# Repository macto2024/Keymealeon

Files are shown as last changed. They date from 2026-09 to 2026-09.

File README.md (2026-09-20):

## Inspiration

Imagine a mechanical keyboard with an OLED display built into each keycap, where every key can change based on what you’re doing. 

That was the idea behind Keymaeleon. Instead of memorizing shortcuts or reaching for different controls in every app, we wanted the keyboard itself to understand the current context and show the actions that matter most. 

For developers, that means the keys can react to things like running tests, debugging, Git changes, or errors, and surface useful actions right when they’re needed.

## What it does

Keymaeleon is a mechanical keyboard with an OLED display built into each key.

A desktop app keeps track of what application is currently active and changes both what the keys display and what they actually do.

We focused a lot on VS Code. Depending on what’s happening while you’re coding, the keyboard can show actions like:

* Run Tests
* Debug
* Explain
* Fix
* View Diff
* Approve
* Reject
* Commit

The cool part is that the keyboard can react to more than just which app is open. It can also react to what’s happening inside that app.

For programs we haven’t specifically built support for, we use the OpenAI API to generate a control profile and suggest actions that might be useful.

## How we built it

On the hardware side, we used an Arduino Nano ESP32 connected to mechanical switches and individual OLED displays.

The Arduino is responsible for reading key presses, updating the OLEDs, communicating with the computer over USB serial, and sending keyboard/media HID events.

On the computer, we have a Python service that acts as the main bridge between the keyboard and the software running on the machine.

For VS Code, we built an extension that can see things like the active file, Git state, test results, terminal activity, debugging state, and other workspace information.

That context gets sent to the Python service, which decides what should be shown on the keyboard. We can also use OpenAI to help pick actions that make sense for the current situation.

## Challenges we ran into

One of the hardest parts was figuring out what the keys should actually show.

Knowing that VS Code is open is easy. Knowing that the user just ran a test, got an error, and would probably benefit from a “Fix” or “Explain” button is much harder.

That’s why we ended up focusing heavily on developers and building a VS Code extension. It gave us much better context about what the user was actually doing instead of just knowing which window was in focus.

Another challenge was making the keyboard useful outside of the few programs we had time to build integrations for.

We didn’t want Keymaeleon to only work with a small list of supported apps, so we added a system that detects the active window and can use the OpenAI API to come up with useful controls for unfamiliar applications.

That gave us a way to make the keyboard useful in a lot more situations without manually building a profile for every program.

## Accomplishments that we're proud of

The part we’re most proud of is that Keymaeleon actually exists as working hardware.

It’s not just a mockup of what an adaptive keyboard could look like. The physical keys really update while you use the computer, and their functions can change in the middle of a workflow.

Seeing a real key change from something like “Run Tests” to “Fix” after an error happens is probably the moment where the project started to feel real.

## What we learned

A big thing we learned is that more options don’t automatically make an interface better.

At first, it was tempting to put as many actions as possible on the keyboard. But the more useful version was usually the one that showed a small number of actions that made sense right now.

We also learned a lot of very different things while building this: VS Code extensions, serial communication, USB HID, OLED rendering, WebSockets, and how to use AI in a way that’s constrained enough to produce predictable controls instead of random suggestions.

## What's next for Keymaeleon

There are a lot of directions we’d like to take it.

We want to go deeper on developer workflows with better Git and debugging controls, more Codex integration, and things like Sentry-powered incident workflows.

We’d also like to improve browser awareness and make automatically generated profiles for unsupported applications more capable.

And, eventually, we want to try larger keyboard layouts.

The main idea would stay the same though: instead of having one fixed keyboard for every task, the keyboard should change with what you’re doing.

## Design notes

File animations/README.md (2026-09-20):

# Animation Lab

A separate test sketch and Python GUI for the existing **Arduino Nano ESP32** and two **SSD1306 64 × 32** OLEDs. The main firmware and companion are unchanged. This sketch only animates displays; it sends no keyboard or media actions.

## Flash

1. Stop the normal companion and close Serial Monitor.
2. Open `AnimationTest/AnimationTest.ino` in Arduino IDE.
3. Select **Arduino Nano ESP32**, using **Arduino ESP32 Boards by Arduino**, and install **U8g2 by oliver**.
4. Use the same USB settings as the main sketch: **Normal mode (TinyUSB)**, **By Arduino pin (default)**. Upload.

Wiring is unchanged: left OLED SDA=A4, SCL=A5; right OLED SDA=D4, SCL=D5. Both use address 0x3C on separate buses. Buttons D2 and D3 connect to GND, using internal pull-ups. OLED power is 3.3 V. The sketch retains the project's `64X32_1F` driver. Both displays now use separate ESP32 hardware I²C controllers (`Wire` and `Wire1`) at 400 kHz, with explicit callbacks and the same pins; no rewiring is needed.

## Run

From the repository root:

```bash
.venv/bin/pip install -r animations/requirements.txt
.venv/bin/python animations/animations.py
```

Tk is also required (`sudo apt install python3-tk` on Ubuntu). Without pyserial the GUI still supports previews.

Select or type the serial port, then click **Connect**. Settings are sent automatically as you adjust them. The GUI shows the most recent full-frame transfer time for each display and cumulative I²C transmission errors since boot. Timings remain at the last measured value while a display is idle; they measure transfer duration, not total frame time. **Test press** triggers that key on the board and in the preview; physical button presses also update the preview. You can preview without connecting hardware.

## Effects

- **Invert (hold):** invert the entire image while a physical button is held; release restores it. GUI test presses last 450 ms.
- **Bottom wave:** each press launches another inverted ring from the bottom-middle; existing rings keep moving. Thickness is 1–16 pixels; speed is 5–160 pixels/second.
- **Center ripple:** the same ring grows from the screen center.
- **Wipe:** an inverted vertical band crosses the screen.
- **Dissolve:** a repeatable scattered-pixel transition inverts the image, then restores it.
- **Sparkle:** scattered pixels shimmer; thickness sets density.

Both screens show a play symbol inside a border so the pixel inversion is easy to see. Settings apply to both screens, but buttons animate independently. Bottom waves stack independently on every press, with up to 32 waves per key (the oldest is replaced at the limit). Overlapping rings merge rather than cancel. Other modes restart on each press. Except for invert, effects run once and finish even if the button is released. Changing settings cancels current effects. Speed affects all timed effects; thickness affects rings, wipe, and sparkle, but does not affect invert or dissolve.

The board runs effects locally and works without the GUI. On boot it defaults to bottom wave, thickness 5, speed 45. Settings are kept in RAM and reset on reboot. The GUI preview uses the same pixel formulas, but USB latency and OLED transfer time can make physical timing differ, especially at high speeds. The hardware-I²C change has not been compiled with the Arduino board toolchain or validated on physical hardware here.

To restore normal macro-key behavior, re-upload `firmware/Keymaeleon/Keymaeleon.ino` and run the normal companion.

## Slow refresh troubleshooting

Re-upload the updated sketch and restart the GUI to use hardware I²C and see transfer timings. The earlier software-I²C implementation uses driver delay constants rather than the `setBusClock()` value, so changing that setting alone does not speed it up. The new callback sets the hardware clock with `Wire.begin(..., I2C_HZ)`; change `I2C_HZ` if testing another rate.

At 400 kHz, 256 bytes plus acknowledgement bits need about 5.8 ms per screen before command/transaction overhead. The animation target remains about 30 FPS. Nonzero I²C errors indicate a communication problem; check the wiring and module pull-ups. Timings substantially above that baseline help distinguish transfer stalls from display scan artifacts.

## Checks and serial protocol

```bash
python3 -m unittest discover -s animations -p 'test_*.py'
```

115200 baud, ASCII lines ending in newline:

- `HELLO` → `ANIMATIONS 1`
- `STATS` → `STATS <left transfer µs> <right transfer µs> <left errors> <right errors>`
- `SET <mode 0..5> <thickness 1..16> <speed 5..160>` → `OK <mode> <thickness> <speed>`
- `TRIGGER <key 0..1>` → `TRIGGERED <key>`
- Physical changes emit `BUTTON <key> <pressed 0..1>` after 25 ms debounce.

Mode numbers follow the effect list above. Overlong lines are discarded, malformed commands return `ERROR command`, and serial processing is bounded to keep button sampling responsive.

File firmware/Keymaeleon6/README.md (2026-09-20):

# Keymaeleon 6 — dual hardware I²C, isolated display buffers

Six OLED keys in two rows of three, using an **Arduino Nano ESP32** and **two TCA9548A multiplexers**, one per hardware I²C interface. Each row has its own worker, U8g2 object, actual framebuffer, staging bitmap and transport counters. Both rows can transmit concurrently.

This revision fixes the earlier implementation's U8g2 shared-memory/shared-transfer-state hazards: `IsolatedDisplay.h` binds an independently owned framebuffer and selects the stateless classic SSD13xx command callback. The user confirmed on 2026-09-19 that replacing faulty displays resolved the mux2 hardware fault. The diagnostics remain available for future checks.

Each press runs the Animation Lab bottom wave: **8 pixels thick, 120 pixels/second**, over the current action pictogram. Waves stack independently, merge on overlap and finish after 450 ms. The sketch sends revision-tagged key presses to `companion/keymaeleon_6.py`, which executes Ubuntu X11 actions. It does not send USB HID keystrokes. Without the companion, displays show Idle; local waves and diagnostics still work. See the [six-key launch instructions and layouts](../../README.md#six-key-version--quick-start).

## Wiring

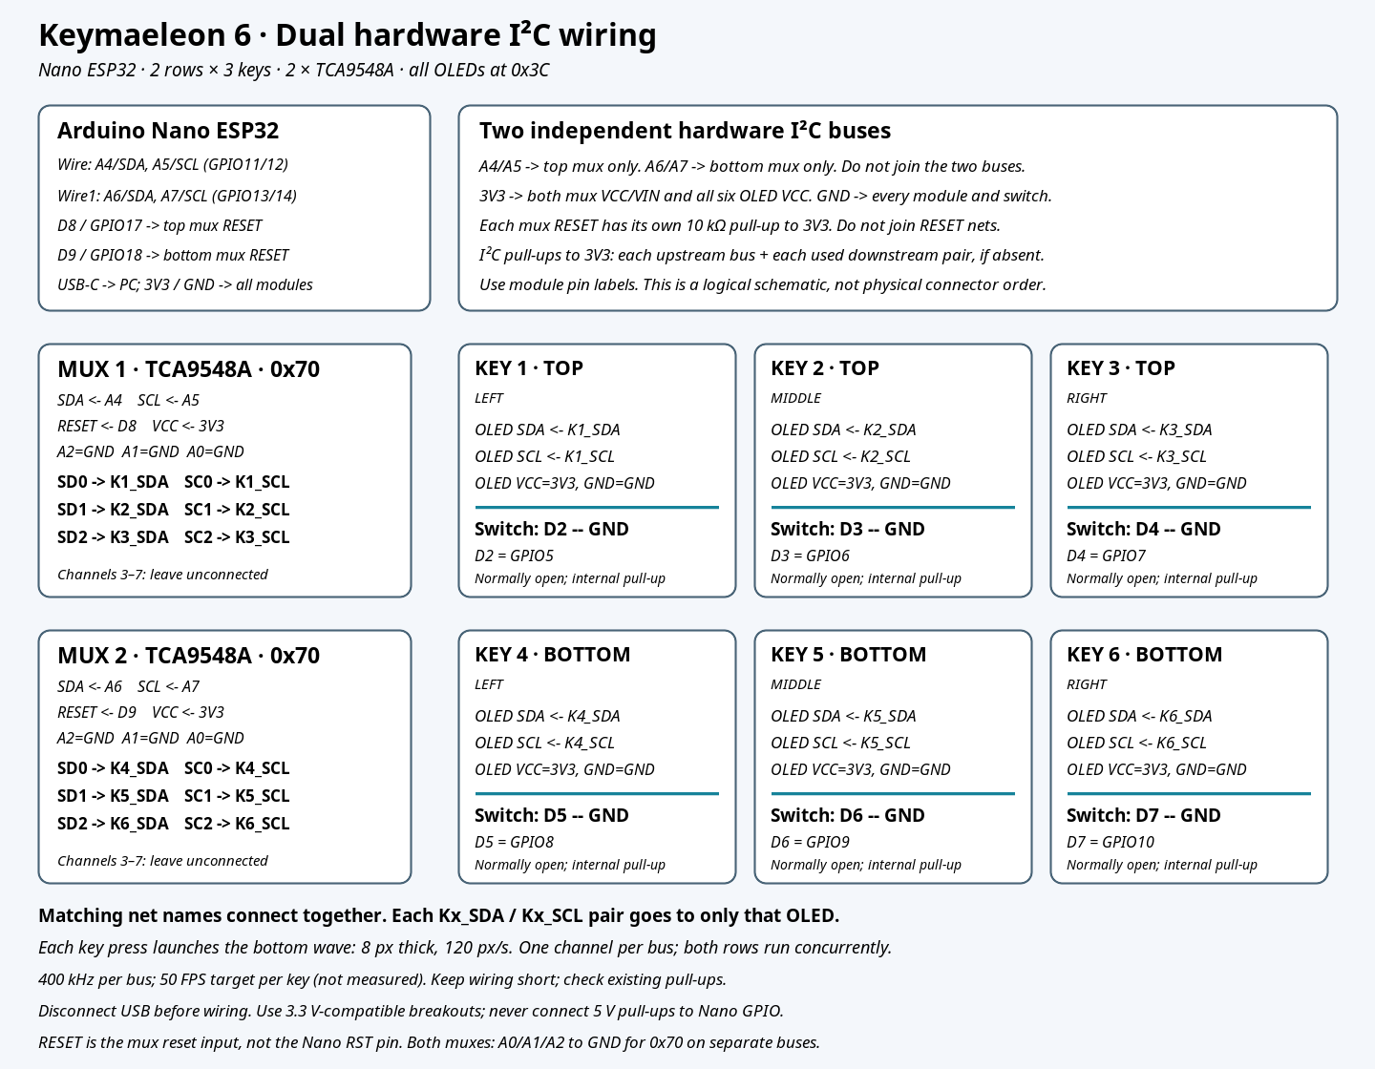
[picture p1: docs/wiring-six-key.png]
Dual-bus wiring


[Scalable SVG](../../docs/wiring-six-key.svg). Matching net names connect together; follow module labels, not connector positions.

**From the single-mux version:** power off. Leave keys 1–3 on channels 0–2 of the top mux. Move keys 4–6 from channels 3–5 to channels **0–2 of the second mux**. Connect its SDA/SCL to **A6/A7** and its RESET to **D9**. Set its address to **0x70**. Do not join the two upstream buses or reset nets.

| Row / bus | Mux address | Nano SDA | Nano SCL | Mux RESET |
|---|---|---|---|---|
| Top / `Wire`, bus 0 | `0x70` | A4 / GPIO11 | A5 / GPIO12 | D8 / GPIO17 |
| Bottom / `Wire1`, bus 1 | `0x70` | A6 / GPIO13 | A7 / GPIO14 | D9 / GPIO18 |

Both mux VCC/VIN inputs and all OLED VCC pins connect to **3V3**, using 3.3 V-compatible breakout modules. All grounds join. USB-C provides board power/data.

| Mux | A2 | A1 | A0 |
|---|---|---|---|
| Top, `0x70` | GND | GND | GND |
| Bottom, `0x70` | GND | GND | GND |

**Both muxes use 0x70**, with A0/A1/A2 grounded. This works because each mux is on a separate hardware bus. If you previously strapped the bottom mux A0 high for 0x71, disconnect power and remove that high strap before grounding A0; never short 3V3 to GND.

| Key | Position | Mux | Channel | OLED SDA/SCL | Switch to GND | GPIO |
|---|---|---|---:|---|---|---:|
| 1 | Top left | Top | 0 | SD0 / SC0 | D2 | 5 |
| 2 | Top middle | Top | 1 | SD1 / SC1 | D3 | 6 |
| 3 | Top right | Top | 2 | SD2 / SC2 | D4 | 7 |
| 4 | Bottom left | Bottom | 0 | SD0 / SC0 | D5 | 8 |
| 5 | Bottom middle | Bottom | 1 | SD1 / SC1 | D6 | 9 |
| 6 | Bottom right | Bottom | 2 | SD2 / SC2 | D7 | 10 |

All OLEDs retain **0x3C**. Leave mux channels **3–7** unconnected. Only one channel per mux is selected at a time; one display on each independent bus can transmit simultaneously. Switches use `INPUT_PULLUP` and connect to GND when pressed.

- Each RESET net needs its own pull-up, typically **10 kΩ to 3V3**, if absent on the breakout. Connect to mux RESET, not Nano RST; do not hard-wire it to 3V3 while driven by a GPIO.
- Each upstream SDA/SCL pair and every used downstream pair needs pull-ups to **3V3**. Breakouts often include them; if absent, start with 4.7 kΩ and verify signal quality. Avoid blindly adding parallel pull-ups.
- Keep wires short, with flexible wires/strain relief at moving keycaps. Use local decoupling if absent, typically 100 nF per module. Never use 5 V pull-ups on Nano GPIO.
- Check the total six-OLED/mux load against available 3.3 V power. With an external regulated peripheral supply, join GND but do not connect its output to the Nano's 3V3 output.

## Upload

1. Stop any serial companion/monitor.
2. Install **Arduino ESP32 Boards by Arduino** and **U8g2 by oliver**.
3. Open `Keymaeleon6.ino`, keeping **Wave.h, IsolatedDisplay.h and Icons6.h** alongside it.
4. Select **Arduino Nano ESP32**, **Normal mode (TinyUSB)**, **By Arduino pin (default)**, then upload.

The OLED driver remains `U8G2_SSD1306_64X32_1F_F_HW_I2C`. The default bus rate is **400 kHz per bus** and target refresh **50 FPS per key**. This is a scheduling target, not a hardware measurement; three displays still share each bus. Wave speed is based on elapsed time, so delayed frames do not slow the animation's timeline.

## Verify and diagnose

Serial Monitor: **115200 baud**, newline endings. Send commands one at a time:

```text
HELLO
SCAN
TEST ALL
STATS
RUN
TRIGGER ALL
```

`HELLO` must report `KEYMAELEON6 DUAL_I2C COMPANION_1 WAVE 8 120`.

**SCAN, TEST, RUN, HZ and REINIT produce two DONE lines, one for each bus. Wait for both before sending the next command.** Output order may vary because the workers run concurrently. Individual lines are serialized so characters do not mix.

`TEST ALL` writes static patterns labelled KEY 1–6 and leaves both rows paused. `RUN` restores the base image and enables animations. `TRIGGER 3` / `TEST 3` mean physical key 4, now **bus 1, channel 0**. All serial key arguments remain global **0–5**. `TEST 3` pauses both rows but tests only key 4.

Other commands: `HZ 100000`, `HZ 400000`, `REINIT`, `REINIT REVERSE`. Rates/reinitialization apply independently to both buses and leave them paused. Reverse initialization is channels 2,1,0 on **each** mux. Scans probe all eight channels per mux, but only 0–2 should have OLEDs.

STATS reports each bus's state/rate and per-display availability, errors, frames and frame intervals. `IO KEY` lines include bus/channel, probe result, last nonzero error, short writes, maximum transaction bytes and transaction count. Historical errors remain until reboot; successful reinitialization is not blocked by them.

A mux failure disables/resets only its row. A display transmission failure disables that display and prints a FAULT line. Each worker owns its queues, bus, reset and memory; only diagnostic logging is shared. The two-key Python companion/Animation Lab GUI does not control this six-key diagnostic protocol.

See [DEBUGGING.md](DEBUGGING.md) for interpretation and a low-speed test sequence. [Validation notes](../../docs/validation.md) distinguish software checks from unperformed hardware tests.

References: [TI TCA9548A datasheet](https://www.ti.com/lit/ds/symlink/tca9548a.pdf), [ESP32 hardware I²C API](https://docs.espressif.com/projects/arduino-esp32/en/latest/api/i2c.html), [Nano pinout](https://docs.arduino.cc/resources/pinouts/ABX00083-full-pinout.pdf).

## Companion protocol and artwork

`HELLO` identifies capability `COMPANION_1`. The host sends `RUN`, then `SET6 <revision> <profile>` every 500 ms; profile IDs are Idle=0, Firefox=1, VS Code=2, Terminal=3, Spotify=4, Desktop=5. Revisions are nonzero 32-bit values. Each row receives the latest layout through its own mailbox; the existing bus/worker/framebuffer isolation remains intact.

A button-down produces `PRESS6 <sequence> <displayed-revision> <key>` with key 0–5, alongside the diagnostic BUTTON line. The displayed revision is recorded after a successful frame transfer. The companion ignores repeated sequences, stale revisions, unavailable focus and unknown apps. Firmware sends `BOOT6` on startup, and returns to Idle after 1.5 seconds without SET6. Diagnostics that pause rendering also suppress companion press events; stop the companion before using Serial Monitor.

`tools/generate_six_icons.py` generates `assets/icons_6.json` and `Icons6.h` from the original icons plus six-key artwork. Run it with Pillow installed after changing layouts/artwork, then reflash. Runtime Python needs no Pillow. The simulator and firmware use the same generated pixels and profile order.

### Live VS Code pictographs

The bridge adds capability `ICON6_1` and `ICON6 <revision> <id0> … <id5>`.
Each ID indexes the generated `sixIconCatalog` in `Icons6.h`; the companion uses
identically ordered `assets/icons_6.json` icons. All six IDs are validated before
one layout is sent to both workers. Profile 8 is reserved for this atomic dynamic
layout; original SET6 profiles, generated text, waves, stale-press rejection and
watchdog behavior remain intact. Regenerate both assets with
`python3 tools/generate_six_icons.py` and reflash after changing the catalogue.

`ICON6_LABELS_1` adds VS Code-only icon-and-label bitmaps to the catalogue. The
icon occupies the top 22 pixels; a centered 5×7 uppercase label occupies rows
25–31. The complete bitmap, including its label, participates in the existing
wave animation. Other app profiles retain their original full-size pictograms.
Flash the updated sketch with `Icons6.h` to enable labels; the companion keeps
using the original icon IDs on older `ICON6_1` firmware and logs an upgrade hint.

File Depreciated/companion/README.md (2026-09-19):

# Companion — driving the keyboard from the backend

The bridge is a **display**, not a brain. The backend resolves which six actions belong on the
keys and publishes them; the bridge maps each action to a pictogram, writes it to the firmware,
and sends presses back. It never decides what a key should be — if it did, the keyboard and the
on-screen client would drift, and a cap would eventually disagree with the action its own press
dispatches.

```
backend :5173  ──SSE /api/events──►  bridge  ──SETK6──►  firmware  ──►  six OLED caps
      ▲                                                      │
      └───────── POST /api/key ◄────── PRESS6 ◄──────────────┘
```

## Run it

```sh
npm start                                              # backend, from the repo root
python3 companion/keymaeleon_bridge.py --simulate      # no hardware: draws the caps in the terminal
python3 companion/keymaeleon_bridge.py --port /dev/ttyACM0
```

No dependencies. Serial uses `termios` from the standard library, not pyserial — a machine that
cannot reach PyPI is a bad place to discover an install step.

If the device will not open, you are probably not in the `dialout` group:

```sh
sudo usermod -aG dialout $USER     # then log out and back in
```

## Flash first

The firmware must be the regenerated one. `HELLO` has to answer with **`COMPANION_2`**; the bridge
refuses to run against older firmware rather than silently showing the wrong caps.

```sh
python3 tools/generate_six_icons.py      # rewrites Icons6.h and assets/icons_6.json
# then open ESP32 Firmware/Keymaeleon6/Keymaeleon6.ino in Arduino IDE and upload
```

## Two revisions that are one number

The backend stamps every layout with `keyboard.layout_revision`. The firmware records the revision
it *actually had on screen* when a key went down and reports it in `PRESS6`. The bridge passes that
straight back to `POST /api/key`.

So a press that raced a context change is rejected by the backend with **409** instead of firing
whatever replaced it. The user pressed what they saw, or nothing happens. Verified:

```
firmware -> bridge   PRESS6 1 102 0        (a revision the cap was not showing)
bridge log           Key 1 ignored: Keys changed. Try the current layout.
```

## Testing without hardware

`fake_firmware.py` opens a pseudo-terminal, launches the bridge against it, and speaks the firmware
side of the protocol. The bridge takes exactly the same code path it uses with a real Arduino.

```sh
python3 companion/fake_firmware.py --press 4 --after 2     # press K and watch the layout change
python3 companion/fake_firmware.py --press 0 --stale       # prove a stale press is refused
```

This proves the transport, handshake, resend timer, revision discipline and press round trip. It
proves nothing about I²C, the displays or the wave animation — those need the device.

## Protocol

| Direction | Line | Meaning |
|---|---|---|
| → firmware | `HELLO` | Sent every second until answered |
| ← firmware | `KEYMAELEON6 DUAL_I2C COMPANION_1 COMPANION_2 WAVE 8 120` | Capabilities |
| → firmware | `RUN` | Leave diagnostics, start rendering |
| → firmware | `SETK6 <revision> <i0..i5>` | Six pictogram ids, one per cap |
| → firmware | `SET6 <revision> <profile>` | The original fixed app profiles, still supported |
| ← firmware | `PRESS6 <sequence> <displayed-revision> <key>` | A key went down |
| ← firmware | `BOOT6` | Rebooted; the bridge re-handshakes |

`SETK6` is re-sent every 500 ms because the firmware falls back to Idle after 1.5 s of silence.
The bridge reads the event stream on a separate thread for exactly this reason: server-sent events
block until the next one arrives, which on a quiet context is the 15-second heartbeat, and the caps
would go blank for most of a demo.

## Status

Everything above is verified against the simulated firmware. **None of it has run against the real
keyboard yet** — the device was not connected to the machine this was built on. The first hardware
session should check, in order: that `HELLO` answers with `COMPANION_2`, that a layout appears on
all six caps, that channels 3–5 land on the second mux, and that a physical press reaches the
backend.

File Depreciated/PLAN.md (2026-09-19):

# Keymaeleon — build plan

Date: 2026-09-19
Target: the 3:30 demo in [DEMO.md](DEMO.md), on Linux. Hardware connection is deferred.

## What already exists

Before planning anything, the honest inventory. Most of the pipeline is built.

| Piece | Where | State |
|---|---|---|
| VS Code context source | `vscode-extension/extension.cjs` | **Works.** Reports active file, language, selection, unsaved count, diagnostics with file/line/severity, window focus, terminal state |
| Editor command execution | same | **Works.** Opens files, diffs, terminals, Problems, Git; runs the agent CLI; **inserts text into the agent terminal** |
| Decision logic | `live.js` | **Works.** Resolves one layer per context, with the reason it won and per-key disabled reasons |
| Context aggregation | `server/runtime.js` | **Works.** Git state, content fingerprinting, real test process with TAP-aware classification |
| Agent lifecycle | `server/agents.js` | **Works.** Tails Codex/Claude session transcripts: working vs. finished, patched files, last command exit code |
| Editor bridge | `server/editor.js` | **Works.** Heartbeat, command queue, acknowledgement, path confinement |
| Six-key display | `index.html`, `app.js`, `style.css` | **Works.** Renders the caps, streams events, posts presses |
| Tests | `test/` | 33 passing |
| Firmware | `ESP32 Firmware/Keymaeleon6/` | **Works on hardware.** Dual-bus I²C, six OLEDs, wave animation, `SET6`/`PRESS6` protocol |
| Serial companion | `ESP32 Firmware/Keymaeleon6/keymaeleon_6.py` | **Cannot run.** Missing `keymaeleon.py` and `assets/icons_6.json`; Ubuntu X11 only |

So the demo does not need a VS Code extension written, and it does not need the key-selection logic written. Both exist.

## The correction worth making

The instinct was "write the VS Code extension and a Python program that shows the right keys." Two things to adjust:

**The extension is written.** It needs two small additions (below), not a build.

**The Python program's only unique job is the hardware.** Icons and serial. Everything upstream of that — context, decisions, labels — already exists in the Node backend, and there is already a display client rendering six keys. Writing Python now means maintaining a second display surface and a second copy of the decision logic, and they will drift.

Since hardware is deferred, **Python is deferred with it.** When it arrives it should not re-derive anything: it subscribes to the backend's existing event stream and posts presses back to the existing endpoint.

## Architecture

One brain. Many sources. Interchangeable displays.

```
  VS Code extension  ─┐
  Codex session logs ─┤
  Git + test process ─┼──►  Node backend  ──► live.js  ──►  six actions
  Browser error hook ─┤       (:5173)                          │
  Foreground app     ─┘                                        │
                                          ┌──────────────┬─────┴────────┐
                                     browser client   Python+serial   (future
                                      (today)          (later)        hardware)
                                          └──────────────┴──────────────┘
                                                   POST /api/key
```

The contract between the brain and any display is the API that already exists: `GET /api/events` for the stream, `POST /api/key` with `{slot, revision}` for a press. The Python companion becomes a *client* of that, not a parallel implementation. Its `Controller` class already has the right discipline — revision bumping, stale-press rejection — so it ports rather than rewrites.

## Build order

Sequenced so the demo is rehearsable as early as possible, and each step leaves something demonstrable.

### 1. The demo app — DONE

`demo/` — a checkout page with the bug in two halves. `src/format.js` has a rounding defect three
tests catch and an agent fixes in one line. `src/cart.js` multiplies a display string by a quantity
and yields `NaN`, and no test touches it because every fixture uses numeric prices.

Verified: **before** 4 passed / 2 failed, page shows `$NaN`; **after the fix** 6 passed / 0 failed,
page still shows `$NaN`. The wall is a property of the code, not of the script.

### 2. Browser error reporting — DONE

`demo/src/report.js` posts to `POST /api/browser/report` on `window.onerror`, unhandled rejections
and a three-second heartbeat. `runtime.setBrowser` clips every field as untrusted text; silence for
ten seconds drops a standing error rather than leaving it current, because a closed tab reports
nothing and neither does a page that crashed before it could speak.

The endpoint answers cross-origin because the page has its own origin, and is the only one that
does: loopback-bound, exact-origin allowlist, 8 KiB cap, and it dispatches nothing. Six tests.

### 3. Two new layers in `live.js`

- **Browser error, tests passing** — the wall. `Console · Revert Codex · View Diff · Ask Codex + error · More · Back`. Wins over the ordinary editing layer, sits below any explicit operation.
- **Tests failed** already exists; the new one is that a *browser* error outranks green tests, because green tests plus a broken page is a more urgent fact than either alone.

Layer precedence stays as it is otherwise. Both layers get tests, like the existing ones.

### 4. `Ask Codex with this error` — the key that justifies the project

The promise: the key carries the error into the prompt and the human never copy-pastes.

The mechanism already exists — `editor_agent_insert` inserts text into the agent terminal without pressing Enter, so the developer still reads it before sending. What is new is composing the prompt from context: the console error, the file, and the failing test. One new action ID, one composer, no new extension command.

Two small extension additions support this and the rest of the run:

- report the dev-server/agent terminal state needed to decide the key is available,
- a revert command for `I — Revert Codex`, scoped to exactly the files the agent patched.

### 5. Scene runner — the safety net

A script that replays the nine beats as context patches through the real `live.js`, so the whole run can be rehearsed without VS Code, Codex, or a network. Also the fallback if something dies on stage.

It is a fallback, not the plan. The difference matters: the beats it replays are the same contexts the live system produces.

### 6. Rehearse

Full run twice without a reset. Time each beat against the sheet.

## Hardware — built, not yet run on the device

- **Icon generator — DONE.** `tools/generate_six_icons.py` recovers the 21 shipping pictograms from
  the existing header byte for byte and never redraws them, then draws 13 new ones from vector
  primitives with no third-party dependency. Verified: all 21 preserved, `sixProfiles` identical.
- **Firmware `SETK6` — DONE, unflashed.** Per-key icon ids beside the existing `SET6`, which expands
  a profile into the same six-icon array so there is one draw path. `HELLO` now answers
  `COMPANION_2`. The parser was extracted and compiled standalone: 11 cases, including out-of-range
  ids, negative ids, reserved revision 0, short lines and trailing garbage.
- **Bridge — DONE.** `companion/keymaeleon_bridge.py`. Stdlib only; serial through `termios`.
  Verified end to end against a pty firmware: handshake, capability refusal, 500 ms resend, press
  round trip that advanced the backend a page, and a stale press correctly refused with 409.
- **The backend now publishes the resolved layout.** A display must never re-derive which six keys
  to show, or the keyboard and the browser client drift.
- **Still to do on the device:** flash it, confirm `COMPANION_2`, confirm all six caps render, and
  confirm a physical press reaches the backend. Nothing here has touched real hardware.
- **The X11 action layer now fits.** `keymaeleon_6.py` shells out to `xdotool`, `pactl`, `playerctl` and `nautilus`, which is exactly right on Linux. Moving the demo off macOS turned this from a rewrite into a port.
- **`keymaeleon.py`.** Missing, and imported by `keymaeleon_6.py`. Ask Michael whether it exists elsewhere before rewriting; its `Focus` and `classify` are worth reading even though the X11 parts get replaced.

## Integration milestones, after the demo

What "make it actually work" means. None of this blocks the demo.

1. **Error-driven keys, live.** Diagnostics and `context.agent.last_command.exit_code` are already observed and published but drive no layer. Smallest real win available.
2. **Real Accept / Reject.** Needs the approval request's ID and scope, a path back to answer that specific request, and isolation from unrelated hand edits. Until all three hold, no Accept key renders outside a staged beat — a key that accepts the wrong thing is worse than no key.
3. **Safe shipping actions.** Stage, commit, log, PR, behind explicit review. Git access is read-only until then.
4. **Foreground-app profiles.** The Spotify/Chrome/Terminal profiles already in `Icons6.h`, driven by real app detection rather than a beat.

## Housekeeping

- **Restore the technical README.** `f968bb6` replaced it with the hackathon narrative. The API reference, configuration table and observation sources are recoverable from `git show 7d660ce:README.md` — restore as `BACKEND.md`, leave the narrative at the root.
- The duplicate root `Keymaeleon6/` was removed upstream in `7f09486`. Resolved.

## Recorded decisions

- Six keys, 2×3, `U/I/O` over `J/K/L`. Letters fixed, labels and icons dynamic.
- Deterministic ranking first. The agent does coding work; it does not choose the six keys.
- A key appears enabled only when the integration behind it exists and the action will really happen. Everything else is disabled **with its reason**, or staged and declared out loud.
- Read the agents' own transcripts rather than scraping terminals or driving the CLI.
- Presses carry the layout revision they were drawn from, so a press that raced a context change is rejected rather than firing what replaced it. `POST /api/key` and the firmware's `PRESS6` already agree on this.
- One brain, many displays. A display never re-derives which keys to show.
- Demo runs on **Linux**. This costs the native floating panel, foreground-app detection, the `open -a` app-launch keys and voice capture, none of which the demo uses -- the browser display client replaces the panel. It gains alignment with the firmware companion, which is already Ubuntu X11 (`xdotool`, `pactl`, `playerctl`), so the hardware path is a port rather than a rewrite.
- `requireForeground` must be `false` on Linux. With no native host the backend never learns which app is focused, so the editor bridge would otherwise refuse to adopt a workspace. Verified: the extension's heartbeat alone adopts the folder, sets `keyboard.mode` to `project` and reports Git state.

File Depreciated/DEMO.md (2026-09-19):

# Keymaeleon — the 3:30 demo

## The claim

**The agent sees the code. The keyboard sees the whole workstation.**

Codex reads files, runs tests, and edits. It cannot see the browser. The demo is built on that blind spot: a bug where **the tests pass and the app is still broken**. Codex declares victory and stops. Only something watching the whole machine knows it isn't done.

That is not a contrived failure. It is the most common way agent-assisted work actually goes wrong.

## The bug

A checkout page renders `Total: $NaN`.

The unit test feeds the formatter a **number** and passes. The real API returns the price as a **string**. Codex fixes the rounding, the test goes green, and the page is still broken. The fix it cannot reach is visible only in the browser console:

```
TypeError: cart total is not a number — API returned price as "$149.00"
```

One bug, one blind spot, legible in four seconds on screen.

## Beat sheet — 210 seconds

| Time | Len | On screen | The six keys | Why they changed |
|---|---|---|---|---|
| **0:00** | 20s | Chrome: `Total: $NaN`, VS Code beside it | Run Tests · Git Diff · Problems · **Ask Codex** · More · Context | Editing a connected project |
| **0:20** | 25s | Type an edit in `src/format.js`, don't save | ~~Run Tests~~ · Git Diff · Problems · Ask Codex · More · Context | **U dims:** *"Save your files before running tests."* |
| **0:45** | 25s | Save, press **U** — real run, real failure | First Failure · Test Output · Rerun · **Ask Codex to investigate** · More · Back | Tests failed, exit 1 |
| **1:10** | 30s | Press **J** — Codex opens in the terminal and starts | Focus Terminal · Git Diff · Problems · Test Output · More · Context | Its session reports a turn in flight |
| **1:40** | 20s | Codex finishes. Press **I** — **tests pass** | Git Diff · Run Tests · Output · Codex · More · Context | Green, and current |
| **2:00** | 25s | **Alt-tab to Chrome. Still `$NaN`.** Hold the silence. | Console · Reload · Network · **Ask Codex with this error** · More · Back | Passing tests, broken app |
| **2:25** | 30s | Press **O** → the reported type error | **Console · Revert Codex · View Diff · Ask Codex + error · More · Back** | ← the payoff |
| **2:55** | 20s | Press **J**. Codex gets the real error, fixes it. `Total: $188.98` | Git Diff · Run Tests · Output · Codex · More · Context | Verified in both places |
| **3:15** | 15s | Land the claim | Stage · Commit · Git Log · Push · More · Back | Reviewed, green, Git available |

## The three beats that carry it

### 0:20 — the dimmed key

`U` greys out and reads *"Save your files before running tests."*

Twenty-five seconds in, before any AI is involved. A mockup never has a reason to refuse. This beat buys credibility for everything after it, which is why it goes early and why it does not get cut for time.

### 2:00 — the wall

Say almost nothing:

> *"Tests pass. Codex is done. And the bug is still there. Codex only ever saw the code — it couldn't see this."*

Then stop talking for a beat. The silence is the demo.

### 2:25 — the decision surface

This is the argument:

> *"Right now there isn't one obvious next move. There are five — look at the console, revert what Codex did, read the diff, send it back with more context, or start over. That's exactly when six keys beat a menu."*

The state is genuinely ambiguous: tests green, app broken, agent idle, tree dirty. So the keyboard stops being a shortcut pad and becomes a **choice**.

Note that `I — Revert Codex` appears here and nowhere else in the run. It exists only because the working tree is dirty *from an agent turn*. That specificity is the point.

## Talk track

**0:00** — "This is a checkout page, and the total is NaN. Six keys on the left; every one of them changes with what I'm doing."

**0:20** — "I've made an edit but haven't saved. The Run Tests key went dark, and it says why: it won't run tests against files that aren't on disk yet."

**0:45** — "Saved. Run. That's a real test process — real exit code. The keys reorganised around the failure: first failure, output, rerun, or hand it to Codex."

**1:10** — "I'll hand it over. While Codex works, the keys follow the agent, not my cursor — and it knows what I asked for, because it's reading Codex's own session log."

**1:40** — "Codex is done. It touched one file. Run the tests — green. Normally this is where the demo ends."

**2:00** — *(switch to Chrome)* "Tests pass. Codex is done. And the bug is still there. Codex only ever saw the code — it couldn't see this."

**2:25** — "Right now there isn't one obvious next move. There are five. That's exactly when six keys beat a menu. I'll look at the actual error — and now this key sends that error straight back to Codex. I don't copy anything."

**2:55** — "Now it has what it was missing. One eighty-eight ninety-eight."

**3:15** — "The agent sees the code. The keyboard sees the editor, the test process, the agent's own session log, Git, and the browser. That's why it could offer the one action the agent couldn't."

## Real vs. staged

State this once, out loud, rather than let it surface in Q&A.

**Real** — the unsaved-file refusal; the test process and its exit code; Codex's working/finished lifecycle, read from its own session transcript; which files it patched; Git dirty state. Beats 0:20 through 1:40 are genuine backend behaviour today.

**Real, now built** — the browser error. `demo/` is a working checkout page whose test suite goes green on the agent's fix while the page stays broken, and `demo/src/report.js` reports that to the backend the way a Sentry SDK would. The wall is a property of the code, not of the script.

**Staged** — `Revert Codex` and the commit layer at 3:15.

## Production notes

- **Cut 3:15 first if over time.** The argument is complete when the browser shows `$188.98`. Ending on "and then we committed" is weaker than ending on the claim.
- **`Ask Codex with this error` is the most impressive key in the run.** The promise is that it carries the console error into the prompt and the human never copy-pastes. If only one new thing gets built for this demo, it is this.
- **Rehearse the alt-tab at 2:00.** The cut from green tests to a broken page is the whole turn; a fumbled window switch costs it.
- **Two screens.** Keys on one, work on the other, so the audience never has to choose where to look.
- **The browser display client carries the words.** The caps are 64×32 and cannot render "Codex finished and changed 2 files". The screen shows labels and the layer's reason; the keyboard shows the actions.

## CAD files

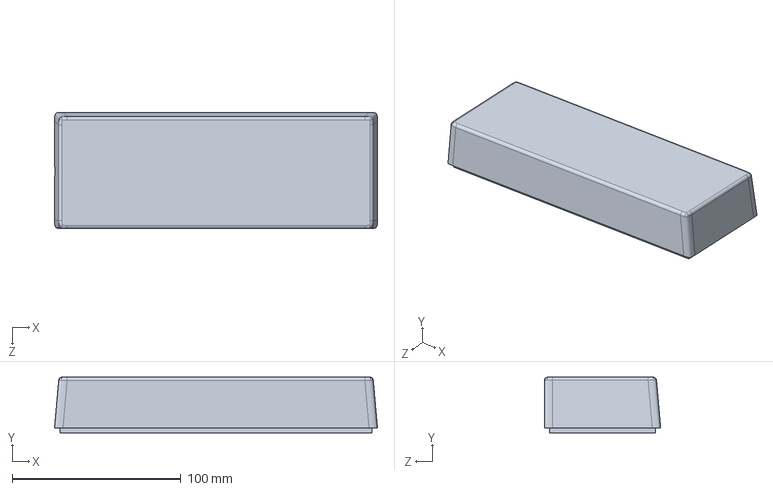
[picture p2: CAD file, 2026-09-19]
CAD/new_base_lid.SLDPRT
191.3 x 33.0 x 68.9 mm

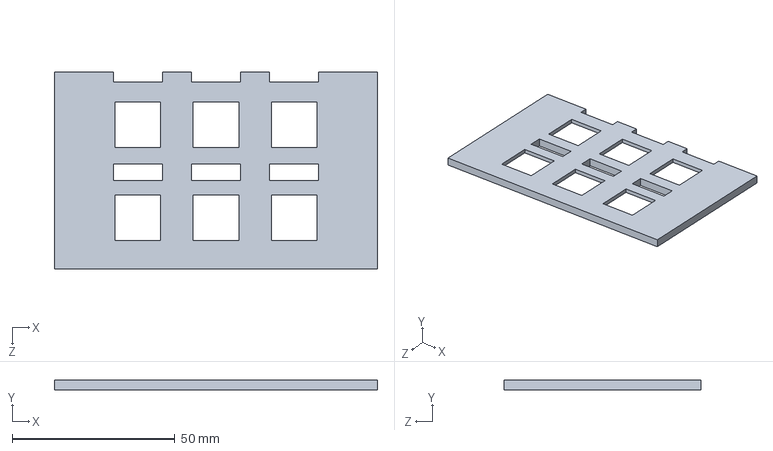
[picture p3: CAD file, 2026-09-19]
CAD/new_key_plate 1.SLDPRT
99.2 x 3.00 x 60.5 mm

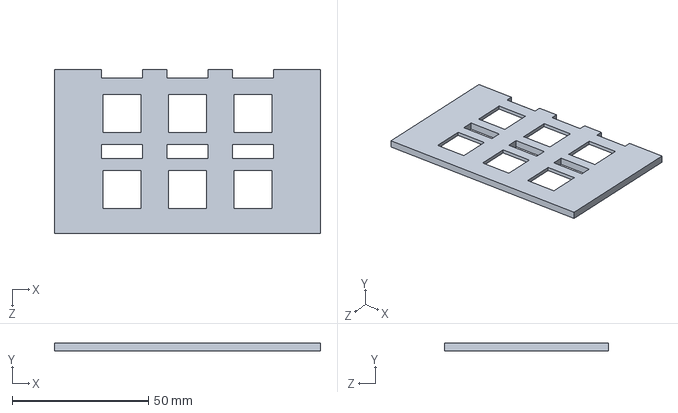
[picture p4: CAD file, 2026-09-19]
CAD/new_key_plate.SLDPRT
97.6 x 3.00 x 60.0 mm

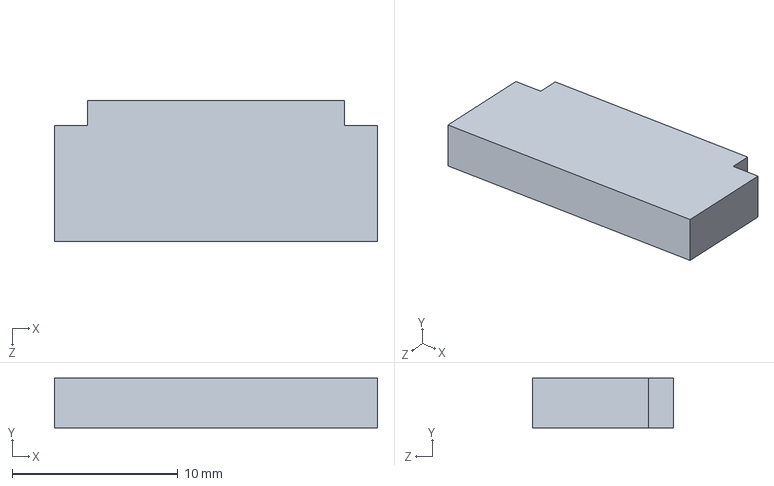
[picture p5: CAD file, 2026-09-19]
CAD/new_small_lid 1.SLDPRT
19.5 x 3.00 x 8.50 mm

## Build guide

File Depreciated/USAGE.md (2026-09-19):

# Using the backend with VS Code and the keyboard

How to get from a fresh clone to six keys that change as you work.

## The three pieces

| | What it is | Who runs it |
|---|---|---|
| **backend** — `server/` | a Node program: watches your work, decides the six keys | you — `npm start` |
| **extension** — `vscode-extension/` | a VS Code plugin: reports the editor, executes editor actions | VS Code loads it |
| **bridge** — `companion/` | a Python program: draws the keys on the keyboard, sends presses back | you — `python3 …` |

Only the backend decides anything. The extension is a sensor and a pair of hands; the bridge is a
display. Neither works out what a key should be — if they did, the keyboard and the browser would
eventually disagree, and a cap would lie about what it does.

```
  VS Code extension ─┐
  Codex session logs ┤
  Git + test process ┼──►  backend :5173  ──►  live.js decides  ──►  six actions
  Browser page       ─┘                                                   │
                                          ┌────────────────────┬──────────┘
                                     browser display      keyboard bridge
                                          └───── POST /api/key ┘
```

## Prerequisites

Node 18+, VS Code 1.85+, Python 3.8+, Git. Optionally the `codex` CLI for the agent keys.
No `npm install` — the backend has no dependencies, and neither does the bridge.

## Quick start

```sh
git clone git@github.com:macto2024/Keymealeon.git && cd Keymealeon
npm test                     # 33 pass, 0 fail
npm start                    # backend on http://127.0.0.1:5173

native/install-vscode.sh     # install the extension, then reload VS Code
code ~/some/project          # any local git repo with a test command
```

Open **http://127.0.0.1:5173** beside your editor. You should see six keys.

## Step by step

### 1. Start the backend

```sh
npm start
```

```
SIX keyboard backend: http://127.0.0.1:5173
Project: waiting for VS Code
```

It waits deliberately. With `root: null` it adopts whichever VS Code window you focus, so you can
switch projects by focusing a different window rather than editing config.

### 2. Connect VS Code

```sh
native/install-vscode.sh
```

Then **Ctrl+Shift+P → Developer: Reload Window**. Open a project folder and focus it. The status bar
should read **SIX: connected** with the project path as its tooltip.

The folder must be **local and trusted**. Remote-SSH, virtual and untrusted workspaces are declared
unsupported, so the extension will not load in them at all.

The backend should now report the project:

```sh
curl -s -H "Host: 127.0.0.1:5173" http://127.0.0.1:5173/api/context \
  | python3 -c 'import sys,json;d=json.load(sys.stdin);print(d["context"]["project"]);print(" | ".join(k["label"] for k in d["keys"]))'
```

```
/home/you/some/project
Run Tests | Git Diff | Output | Codex in Terminal | More | Context
```

### 3. Configure the project's tests

`six.config.json`:

| Key | Meaning |
|---|---|
| `root` | project folder, or `null` to adopt the focused VS Code window |
| `command` | test command as an array — `["npm","test"]`, `["pytest"]`, `["cargo","test"]` |
| `requireForeground` | must be **`false`** on Linux; there is no foreground-app host |
| `codexModel` | model passed to the Codex CLI |
| `timeoutMs` | test-run timeout, default 60000 |

Restart the backend after editing. If `command` is `null`, Run Tests stays disabled **with that as
its reason** rather than silently doing nothing.

The runner is TAP-aware. Exit zero is a pass; a nonzero exit **with** a TAP failure total is failing
tests; any other nonzero exit is reported as a runner error rather than mislabelled as a failure.
`node --test` emits TAP automatically when not attached to a terminal.

### 4. Pick a display

**Browser** — already running at `http://127.0.0.1:5173`. Shows labels and the reason the current
layer won, which the 64×32 caps cannot.

**Terminal** — the caps as pictograms, no hardware:

```sh
python3 companion/keymaeleon_bridge.py --simulate
```

```
  ┌────────────┬────────────┬────────────┐
  │    run     │    diff    │    list    │
  │  sparkle   │    more    │  context   │
  └────────────┴────────────┴────────────┘
```

**Real keyboard** — see below.

## Use it

Letters never move. Labels do.

```
U — primary     I — secondary     O — inspect
J — agent       K — more          L — back
```

| What you do | What the keys become |
|---|---|
| Editing | `Run Tests · Git Diff · Output · Codex in Terminal · More · Context` |
| Type without saving | **`U` dims** — *"Save your VS Code files before running tests."* |
| Press **U** | tests run; `Output · Stop Tests · …` |
| Tests fail | reason: *"Tests failed with exit 1"* |
| Edit and save after a run | reason: *"Source changed since the last test run"* — the result went stale |
| Press **J** | Codex opens in a `SIX Codex` terminal |
| Codex is working | reason: *"Codex is working on: \<your request\>"* |
| Codex finishes with edits | **`U` becomes a diff of the exact file it patched** |
| Press **K** | more actions; **L** goes back |

A key that cannot fire keeps its slot and shows **why**. It is never hidden and never silently dead.

The two worth watching are the dimmed key and the post-Codex review. The first proves the backend is
reading real editor state; the second is read from Codex's own session transcript in
`~/.codex/sessions/` — nothing polls the CLI, it reports on itself.

## With the real keyboard

Connecting it is not enough — the device must be running the regenerated firmware.

```sh
python3 tools/generate_six_icons.py     # rewrites Icons6.h and assets/icons_6.json
```

Open `ESP32 Firmware/Keymaeleon6/Keymaeleon6.ino` in Arduino IDE (Board: **Arduino Nano ESP32**,
Normal mode (TinyUSB)), keep `Wave.h`, `IsolatedDisplay.h` and `Icons6.h` beside it, and upload.

```sh
sudo usermod -aG dialout $USER          # once, then log out and back in
python3 companion/keymaeleon_bridge.py --port /dev/ttyACM0
```

Check in this order, since each depends on the last:

1. Serial Monitor at 115200: send `HELLO` → the reply must contain **`COMPANION_2`**
2. Send `SETK6 1 4 22 26 25 33 32` by hand → six caps change
3. Start the bridge → caps track the backend
4. Press a key → the backend acts and the layout changes

Steps 1 and 2 need no bridge. If they work, the hard part is done.

The bridge refuses to run against older firmware rather than showing wrong caps.

**None of this has run on real hardware yet.** The whole path is verified against a simulated
firmware over a pseudo-terminal, which exercises the same code, but not I²C, the displays or the
wave animation.

## Testing without any hardware

```sh
python3 companion/fake_firmware.py --press 4 --after 2    # press K, watch the layout change
python3 companion/fake_firmware.py --press 0 --stale      # a stale press is refused
```

The second one demonstrates the safety property. The firmware reports the revision the cap was
*actually showing*; the bridge passes it to `POST /api/key`; if the context moved in between the
backend answers **409** and nothing fires. You press what you saw, or nothing happens.

## Troubleshooting

- **"waiting for VS Code" forever** — the extension is not connected. Hover the VS Code status bar,
  or open Output → **SIX**.
- **"Focus a VS Code project window to select it"** — set `requireForeground: false`. On Linux
  nothing reports which app is focused, so the bridge cannot satisfy that check.
- **"Open this project folder in VS Code: /path"** — the backend adopted a different folder. Open
  that one, or restart the backend.
- **Run Tests always disabled** — either `command` is `null`, or you have unsaved files. The key
  says which.
- **Git keys disabled** — the folder must be a git repository **root**, not a subdirectory.
- **Keys never change** — check the browser display first. If it moves and the keyboard does not,
  the problem is the bridge or the firmware, not the backend.
- **Serial will not open** — you are not in `dialout` yet, or you have not logged out since.

## Not built yet

So you know what you are looking at:

- **The keys do not react to browser errors.** `demo/` reports them and they reach
  `context.browser`, but `live.js` does not read that field, so the layer never changes.
- **A disabled key looks normal on the caps.** `SETK6` carries icons only, with no dim state, so
  the most convincing behaviour in the system is invisible on the hardware.
- **No Accept / Reject.** The agent CLI runs `--sandbox read-only`, so there is no real approval to
  accept. See milestone 2 in [PLAN.md](PLAN.md).
- **No commit, stage or push.** Git access is strictly read-only.

See [PLAN.md](PLAN.md) for the build order, [DEMO.md](DEMO.md) for the demo script,
[vscode-extension/README.md](vscode-extension/README.md) for the extension, and
[companion/README.md](companion/README.md) for the serial protocol.

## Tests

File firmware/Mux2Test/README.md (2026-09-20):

# Mux2-only test

Open **Mux2Test.ino** in Arduino IDE. Select **Arduino Nano ESP32**, **Normal mode (TinyUSB)**, **By Arduino pin (default)**. Install U8g2 and upload. No other sketch files are required.

This is a separate static test: no animation, no extra worker tasks, no Wire/bus0 initialization. It holds **mux1 RESET (D8) LOW** throughout. That disconnects mux1 channels but does not remove OLED power or erase their existing images.

| Mux2 connection | Nano / destination |
|---|---|
| SDA | A6 / GPIO13 |
| SCL | A7 / GPIO14 |
| RESET | D9 / GPIO18; pull-up to 3V3 if absent |
| VCC/VIN | 3V3 (compatible breakout) |
| GND, A0, A1, A2 | GND (address 0x70) |
| SD0 / SC0 | Key 4 SDA / SCL |
| SD1 / SC1 | Key 5 SDA / SCL |
| SD2 / SC2 | Key 6 SDA / SCL |

OLED VCC=3V3, GND common, address 0x3C. **D8 and D9/reset nets must be separate.** Disconnect USB before rewiring. If mux1 is not connected to D8, disconnect its upstream SDA/SCL to ensure it is excluded. Holding its RESET low is not a power-load isolation test; to test supply loading separately, disconnect its peripherals with power off.

At boot the sketch scans the upstream Wire1 bus at **100 kHz**, then sends a static `MUX 2 / KEY 4`, `KEY 5`, or `KEY 6` pattern to channels 0–2. The mux is reset between tests; static OLED images persist.

Open Serial Monitor at **115200 baud**. If startup output was missed, send these one at a time (newline endings are fine):

```text
S
T
?
```

- `S`: reset mux2 and scan upstream addresses. Expect `FOUND 0x70`. A different found address means different straps; no addresses means communication/power/reset/pin trouble before display rendering.
- `T`: test all three OLEDs once. `0`, `1`, `2` test a single mux2 channel.
- `?`: Wire1 initialization result, cumulative display errors, and instantaneous SDA/SCL levels while idle. Low idle lines warrant checking wiring/pull-ups/devices; high levels alone do not prove a healthy bus.

For each channel expect `write_code=0`, readback **1/2/4**, `probe_code=0`, and `transfer_errors=0`. Wire error codes: 2=NACK (normally no device), 5=timeout; other codes are reported as-is. The alternate 0x3D OLED address is probed if 0x3C fails, but this sketch only renders at 0x3C.

**Send the full S/T/? output and which patterns are visible.** If the Nano repeatedly resets/disconnects, report that too.

Re-upload `firmware/Keymaeleon6/Keymaeleon6.ino` afterward to restore both buses. This test has not been flashed or physically verified by the assistant.

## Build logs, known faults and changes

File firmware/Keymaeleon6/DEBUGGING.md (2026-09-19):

# Dual-bus diagnostic build

This revision returns to **two buses/two muxes**, with the software isolation fix applied. Update 2026-09-19: the user replaced faulty displays and confirmed that the mux2 hardware issue is resolved. Wiring is in [README.md](README.md).

## What was fixed

The installed U8g2 2.36.19's `u8g2_m_8_4_f()` gives identical display objects the same static framebuffer. Its default `u8x8_cad_ssd13xx_fast_i2c()` also shares a function-static `in_transfer` flag. Separate objects and staging bitmaps did not isolate either of these; concurrent workers could interfere.

The actual sketch now calls `Keymaeleon6::isolateDisplay()` from `IsolatedDisplay.h` before beginning/drawing each display object. It assigns a row-owned 256-byte framebuffer and the stateless classic command callback. Each worker also has independent wave state, transfer-byte accounting, bus-rate state, command queues and mux-reset pin. A logging mutex protects whole output lines, without locking display transfers together.

A native regression test exercises this exact isolation helper and the installed C library using two threads. Both send 100 frames with different payload patterns; the test checks intact data, independent framebuffers, closed transactions, and a maximum of 25 bytes per transaction. That is below the installed ESP32 Wire default 128-byte buffer. Hardware I²C timing and electrical behavior are separate checks.

## First hardware check

After uploading with **Wave.h, IsolatedDisplay.h and Icons6.h** present, connect all six OLEDs as documented. Serial Monitor: **115200, newline**. Send commands individually:

```text
HELLO
STATS
HZ 100000
SCAN
TEST ALL
STATS
```

Check `HELLO` contains `DUAL_I2C COMPANION_1`. Diagnostic commands finish with **two DONE lines**, tagged `BUS 0` and `BUS 1`; wait for both. HELLO/STATS do not produce DONE. Workers can print their lines in either order.

Expected static images: border, top bars, and **KEY 1–6**. TEST sends one pattern per screen and pauses animation, eliminating continuous animation load. Initialization also sends configuration and clear data. Send back the full output and which numbered patterns appeared if problems remain.

### Channel mapping

| Global serial key index | Physical key | Bus | Channel |
|---:|---:|---:|---:|
| 0 | 1 | 0 | 0 |
| 1 | 2 | 0 | 1 |
| 2 | 3 | 0 | 2 |
| 3 | 4 | 1 | 0 |
| 4 | 5 | 1 | 1 |
| 5 | 6 | 1 | 2 |

Bottom-row displays must move from single-mux channels 3–5 onto second-mux channels **0–2**. Top mux is `0x70`, bottom mux `0x70`. Do not connect A4/A5 to A6/A7 or D8 to D9.

### Scan results

Each bus first disables all mux channels. `SCAN BUS ... OFF` should report `MUX_OK 1`, `MASK_READ 0`, and normally `OLED_3C 2` (no OLED reachable). An ACK at 0x3C while all channels are disabled suggests a bypass/direct connection or another upstream device at that address.

Channels **0–2 on each mux** should report:

- `MUX_OK 1` and decimal `MASK_READ` **1, 2, 4** respectively.
- `OLED_3C 0`: address acknowledged. ACK alone does not prove correct displayed pixels.
- `OLED_3D 2`: normally no alternate-address device. A `0` can indicate a module strapped to 0x3D.

Channels 3–7 should have no OLED ACK. `-1` means a read failed or a probe was skipped. A channel that holds the bus can require mux reset before continuing; results retain the failure. Normal display selections also verify the mux mask before transmitting.

### Error counters

- `PROBE`: latest address probe (0 success, 255 not reached).
- `LAST_ERROR`: last nonzero Wire error, retained after later successful retries.
- `SHORT_WRITES`: Wire accepted fewer bytes than requested; this directly tests a transmit-buffer failure.
- `MAX_BYTES`: largest requested transaction; expect no more than **25** for the classic callback.
- `QUEUE_DROPS`: rejected animation events, not dropped framebuffer data.
- `FRAMES`: attempted frame transfers. Inspect error/availability status as well.
- `INTERVAL_US`: latest frame-start interval (millisecond resolution); during continuous animation FPS is approximately `1000000 / INTERVAL_US`. It includes idle gaps, so inspect during active animation.

Wire codes: 0 success, 1 data too long, 2 address NACK, 3 data NACK, 4 other error, 5 timeout. ESP32 can map some errors broadly. Cumulative counters reset on reboot; TEST's NEW_ERRORS is a per-pattern delta. A FAULT line explains when an I²C error disables a screen, which can otherwise look like a frozen animation.

## Next tests

If static patterns work at 100 kHz, compare at normal speed:

```text
HZ 400000
SCAN
TEST ALL
STATS
RUN
TRIGGER ALL
```

Wait for both DONE lines after each diagnostic command, and about one second after TRIGGER ALL before requesting STATS. Press keys repeatedly to inspect continuous timing. The 50 FPS target is not guaranteed; mux transactions, mask readback and transport overhead reduce achievable rates.

`TEST 3` tests only physical key 4 (bus 1/channel 0), while pausing both rows. `RUN` resumes both. `REINIT REVERSE` resets/retries channels 2,1,0 within each row; inspect STATS before TEST ALL, which initializes in normal order. Mux reset is not a power cycle of OLED modules.

If failures persist at low speed with static patterns:

1. Power off before changing wiring. Test a known-good OLED and signal cable on each suspect mux channel, retaining known-good power/ground connections.
2. Connect displays one at a time and record which addition causes existing displays to fail.
3. Check SDn/SCn pairing, address straps, 3.3 V pull-ups, and that upstream buses/reset lines are separate.
4. Measure 3V3 at the OLEDs with one and six connected; check for repeated Nano resets or USB disconnects. A meter cannot exclude brief dips. Do not tie another supply output to the Nano's 3V3 output.
5. If only 400 kHz fails, investigate wiring length, pull-ups and rise time. A logic analyzer can inspect masks/ACKs; a scope can inspect electrical signals/power.

Reported single-mux symptoms (freezes and blank output with all six connected) remain unverified on hardware. Do not infer their cause solely from the now-corrected dual-worker software issue.

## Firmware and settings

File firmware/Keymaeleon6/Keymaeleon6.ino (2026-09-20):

#include <Arduino.h>
#include <Wire.h>
#include <U8g2lib.h>
#include <atomic>
#include "freertos/FreeRTOS.h"
#include "freertos/task.h"
#include "freertos/queue.h"
#include "Wave.h"
#include "Icons6.h"
#include "IsolatedDisplay.h"
#include "freertos/semphr.h"
#include <stdarg.h>

// Physical layout: 1 2 3 / 4 5 6. App-aware serial companion; actions execute on the host, no HID.
constexpr uint8_t KEY_COUNT = 6;
// Profiles 0-5 are the preset pictogram layouts in Icons6.h; profile 6 draws companion-supplied
// text, used for shortcuts an LLM generated for an app with no preset.
// Profile 7 is the spinner shown while the companion waits for the model.
constexpr uint8_t GENERATED_PROFILE = 6, BUSY_PROFILE = 7;
constexpr uint8_t LABEL_MAX = 24, LABEL_COLUMNS = 12, LABEL_LINES = 3;
// Largest first: a label is drawn in the biggest font its wrapped lines still fit inside.
struct LabelFont { const uint8_t *font; uint8_t columns, height, lines; };
const LabelFont LABEL_FONTS[] = {{u8g2_font_7x13_tf, 9, 13, 2},
                                 {u8g2_font_6x10_tf, 10, 10, 3},
                                 {u8g2_font_5x7_tf, 12, 9, 3}};
constexpr uint8_t BUTTON_PINS[KEY_COUNT] = {D2, D3, D4, D5, D6, D7};
// One TCA9548A per hardware bus; channels 0–2 serve each row.
constexpr uint8_t MUX_ADDRESSES[2] = {0x70, 0x70};
constexpr uint8_t SDA_PINS[2] = {A4, A6};
constexpr uint8_t SCL_PINS[2] = {A5, A7};
constexpr uint8_t RESET_PINS[2] = {D8, D9}; // Active-low mux reset, pulled up to 3V3.
constexpr uint8_t OLED_ADDRESS = 0x3C;
constexpr uint32_t I2C_HZ = 400000;
constexpr uint32_t FRAME_MS = 20; // Target 50 FPS/key; three displays share each independent bus.
U8G2_SSD1306_64X32_1F_F_HW_I2C topOLED(U8G2_R0, U8X8_PIN_NONE);
U8G2_SSD1306_64X32_1F_F_HW_I2C bottomOLED(U8G2_R0, U8X8_PIN_NONE);

// Worker-owned state: never read/written by loop().
struct DisplayState {
  Keymaeleon6::Wave wave;
  bool dirty = true;
  uint32_t lastFrame = 0;
};
struct Row {
  TwoWire *wire;
  U8G2 *oled;
  QueueHandle_t queue = nullptr;
  DisplayState displays[3];
  uint8_t bitmap[256] = {};
  uint8_t framebuffer[256] = {}; // Explicit ownership; U8g2 defaults can share static memory.
  uint8_t textBitmap[3][256] = {}; // Labels rasterized once per layout, then waved like an icon.
  uint32_t rasterized[3] = {};     // Revision each textBitmap was built from; 0 is never generated.
  uint8_t selected = 0;
  Row(TwoWire *w, U8G2 *d) : wire(w), oled(d) {}
} rows[2] = {{&Wire, &topOLED}, {&Wire1, &bottomOLED}};

// Atomic telemetry is safe to inspect from loop() while the display worker transfers.
struct Telemetry {
  std::atomic<bool> available{false};
  std::atomic<uint32_t> transferUs{0}, errors{0}, frames{0}, intervalUs{0};
  std::atomic<uint32_t> shortWrites{0}, transactions{0}, maxBytes{0};
  std::atomic<uint32_t> lastCode{0}, lastBytes{0}, probeCode{255};
} stats[KEY_COUNT];
std::atomic<bool> busReady[2];
std::atomic<uint32_t> muxErrors[2];
enum DebugCommand : uint8_t { SCAN, TEST, RUN, RATE, REINIT };
struct DebugRequest { DebugCommand command; int value; };
QueueHandle_t debugQueue[2] = {nullptr, nullptr};
std::atomic<bool> paused[2];
std::atomic<uint32_t> busHz[2];
uint32_t transactionBytes[2] = {};
bool reverseInit[2] = {};
std::atomic<uint32_t> queueDrops{0};
struct Press { uint8_t channel; uint32_t at; };
struct Button {
  bool raw = HIGH, stable = HIGH;
  uint32_t changed = 0;
} buttons[KEY_COUNT];
struct Layout { uint32_t revision; uint8_t profile; uint8_t icons[KEY_COUNT]; char labels[KEY_COUNT][LABEL_MAX]; };
QueueHandle_t layoutQueue[2] = {nullptr, nullptr};
Layout activeLayout[2] = {}; // Worker-owned.
std::atomic<uint32_t> shownRevision[6];
bool companionActive = false;
uint32_t lastLayout = 0, pressSequence = 0;
// Labels arrive as separate lines before the SET6 that activates them; loop() owns this staging copy.
uint32_t pendingRevision = 0;
char pendingLabels[KEY_COUNT][LABEL_MAX] = {};
char input[128];
size_t used = 0;
bool overflow = false;

SemaphoreHandle_t logMutex = nullptr;
void logLine(const char *format, ...) {
  char text[256];
  va_list args; va_start(args, format);
  vsnprintf(text, sizeof(text), format, args); va_end(args);
  if (logMutex) xSemaphoreTake(logMutex, portMAX_DELAY);
  Serial.print(text);
  if (logMutex) xSemaphoreGive(logMutex);
}

bool muxWrite(uint8_t row, uint8_t mask) {
  TwoWire &bus = *rows[row].wire;
  bus.beginTransmission(MUX_ADDRESSES[row]);
  bus.write(mask);
  if (bus.endTransmission() == 0) return true;
  ++muxErrors[row];
  return false;
}
void busFault(uint8_t row) {
  digitalWrite(RESET_PINS[row], LOW);
  delayMicroseconds(10);
  digitalWrite(RESET_PINS[row], HIGH);
  busReady[row] = false;
  for (uint8_t i = row*3; i < row*3+3; ++i) stats[i].available = false;
  // Reset disconnects every downstream channel after a mux fault.
}
bool selectDisplay(uint8_t row, uint8_t channel) {
  if (!busReady[row] || channel >= 3) return false;
  // One-hot control register replaces any previous selection on THIS mux only.
  if (!muxWrite(row, uint8_t(1U << channel))) { busFault(row); return false; }
  if (rows[row].wire->requestFrom(MUX_ADDRESSES[row], uint8_t(1)) != 1 ||
      rows[row].wire->read() != int(1U << channel)) {
    ++muxErrors[row]; busFault(row); return false;
  }
  rows[row].selected = channel;
  return true;
}
uint8_t displayI2C(u8x8_t *display, uint8_t message, uint8_t count, void *data) {
  const uint8_t row = display == topOLED.getU8x8() ? 0 : 1;
  TwoWire &bus = *rows[row].wire;
  Telemetry &s = stats[row*3 + rows[row].selected];
  switch (message) {
    case U8X8_MSG_BYTE_INIT: return busReady[row] ? 1 : 0;
    case U8X8_MSG_BYTE_START_TRANSFER:
      transactionBytes[row] = 0;
      bus.beginTransmission(u8x8_GetI2CAddress(display) >> 1); break;
    case U8X8_MSG_BYTE_SEND:
      transactionBytes[row] += count;
      if (transactionBytes[row] > s.maxBytes.load()) s.maxBytes = transactionBytes[row];
      if (bus.write(static_cast<uint8_t *>(data), count) != count) {
        ++s.errors; ++s.shortWrites; return 0;
      }
      break;
    case U8X8_MSG_BYTE_END_TRANSFER: {
      uint8_t code = bus.endTransmission();
      ++s.transactions; s.lastBytes = transactionBytes[row];
      // Keep the last failure code until reset, rather than overwrite with success.
      if (code) { s.lastCode = code; ++s.errors; return 0; }
      break;
    }
    case U8X8_MSG_BYTE_SET_DC: break;
    default: return 0;
  }
  return 1;
}
bool initializeDisplay(uint8_t row, uint8_t channel) {
  Row &r = rows[row];
  Telemetry &s = stats[row*3 + channel];
  s.available = false;
  if (!selectDisplay(row, channel)) return false;
  r.wire->beginTransmission(OLED_ADDRESS);
  uint8_t probe = r.wire->endTransmission();
  s.probeCode = probe;
  if (probe) { ++s.errors; s.lastCode = probe; return false; }
  uint32_t before = s.errors.load();
  r.oled->begin();
  r.oled->setContrast(100);
  s.available = s.errors.load() == before;
  r.displays[channel].wave.count = 0;
  r.displays[channel].dirty = true;
  return s.available;
}
void prepareBus(uint8_t row) {
  Row &r = rows[row];
  digitalWrite(RESET_PINS[row], LOW);
  pinMode(RESET_PINS[row], OUTPUT);
  delay(1);
  digitalWrite(RESET_PINS[row], HIGH);
  delay(1);
  busReady[row] = r.wire->begin(SDA_PINS[row], SCL_PINS[row], busHz[row]);
  r.wire->setTimeOut(20);
  if (!busReady[row] || !muxWrite(row, 0)) { busFault(row); return; }
  r.oled->getU8x8()->byte_cb = displayI2C;
  // Own the real U8g2 framebuffer, not just the staging bitmap.
  Keymaeleon6::isolateDisplay(r.oled->getU8g2(), r.framebuffer);
  r.oled->setI2CAddress(OLED_ADDRESS << 1);
  r.oled->setBusClock(busHz[row]);
 }
void initRow(uint8_t row) {
  prepareBus(row);
  if (!busReady[row]) return;
  for (uint8_t index = 0; index < 3; ++index) {
    uint8_t channel = reverseInit[row] ? 2 - index : index;
    initializeDisplay(row, channel);
    if (!busReady[row]) return;
  }
  if (!muxWrite(row, 0)) busFault(row);
}
uint8_t wrapLabel(const char *label, char lines[LABEL_LINES][LABEL_COLUMNS + 1],
                  uint8_t columns, uint8_t maxLines, bool *fits) {
  uint8_t count = 0;
  lines[0][0] = 0;
  *fits = true;
  for (const char *word = label; *word; ) {
    while (*word == ' ') ++word;
    const char *end = word;
    while (*end && *end != ' ') ++end;
    while (end > word) {
      uint8_t size = uint8_t(end - word > columns ? columns : end - word);
      uint8_t length = uint8_t(strlen(lines[count]));
      bool space = length > 0;
      if (length + space + size > columns) {
        if (count + 1 >= maxLines) { *fits = false; return uint8_t(count + 1); }
        lines[++count][0] = 0;
        length = 0; space = false;
      }
      if (space) lines[count][length++] = ' ';
      memcpy(lines[count] + length, word, size);
      lines[count][length + size] = 0;
      word += size; // A word longer than one line continues on the next.
      if (word < end) *fits = false;  // It had to be broken mid-word.
    }
  }
  return uint8_t(count + 1);
}
void rasterizeLabel(uint8_t row, uint8_t channel) {
  Row &r = rows[row];
  U8G2 &d = *r.oled;
  const char *label = activeLayout[row].labels[row*3 + channel];
  char lines[LABEL_LINES][LABEL_COLUMNS + 1] = {};
  const LabelFont *chosen = &LABEL_FONTS[0];
  uint8_t count = 1;
  for (const LabelFont &candidate : LABEL_FONTS) {
    bool fits = false;
    chosen = &candidate;
    count = wrapLabel(label, lines, candidate.columns, candidate.lines, &fits);
    d.setFont(candidate.font);
    for (uint8_t line = 0; fits && line < count; ++line)
      if (d.getStrWidth(lines[line]) > Keymaeleon6::WIDTH) fits = false;
    if (fits) break; // Otherwise keep shrinking; the smallest font is the fallback.
  }
  d.clearBuffer();
  d.setFont(chosen->font);
  uint8_t ascent = d.getAscent();
  // Centre the ink: the first baseline sits one ascent below the top of the text block.
  int top = (Keymaeleon6::HEIGHT - ((count - 1) * chosen->height + ascent)) / 2 + ascent;
  for (uint8_t line = 0; line < count; ++line)
    d.drawStr((Keymaeleon6::WIDTH - d.getStrWidth(lines[line])) / 2, top + line * chosen->height,
              lines[line]);
  // Convert the tiled U8g2 framebuffer into the row-major XBM layout Wave::frame reads.
  const uint8_t *buffer = d.getBufferPtr();
  uint8_t stride = uint8_t(d.getBufferTileWidth() * 8);
  uint8_t *bitmap = r.textBitmap[channel];
  memset(bitmap, 0, sizeof(r.textBitmap[channel]));
  for (uint8_t y = 0; y < Keymaeleon6::HEIGHT; ++y)
    for (uint8_t x = 0; x < Keymaeleon6::WIDTH; ++x)
      if ((buffer[(y / 8) * stride + x] >> (y % 8)) & 1)
        bitmap[y * 8 + x / 8] |= uint8_t(1U << (x % 8));
}
// Twelve dots on a radius-12 circle centred on the screen, starting at twelve o'clock.
constexpr uint8_t BUSY_DOTS = 12;
constexpr uint8_t BUSY_X[BUSY_DOTS] = {32, 38, 42, 44, 42, 38, 32, 26, 22, 20, 22, 26};
constexpr uint8_t BUSY_Y[BUSY_DOTS] = {4, 6, 10, 16, 22, 26, 28, 26, 22, 16, 10, 6};
void drawBusy(U8G2 &d, uint8_t key, uint32_t now) {
  d.clearBuffer();
  // One turn per second, each key a step ahead of the last, so the pad ripples left to right.
  uint8_t head = uint8_t((now / (1000 / BUSY_DOTS) + key) % BUSY_DOTS);
  for (uint8_t dot = 0; dot < BUSY_DOTS; ++dot) {
    uint8_t behind = uint8_t((head + BUSY_DOTS - dot) % BUSY_DOTS);
    if (behind == 0) d.drawDisc(BUSY_X[dot], BUSY_Y[dot], 2);
    else if (behind <= 2) d.drawDisc(BUSY_X[dot], BUSY_Y[dot], 1);
    else if (behind <= 4) d.drawPixel(BUSY_X[dot], BUSY_Y[dot]);
  }
}
void render(uint8_t row, uint8_t channel) {
  if (!selectDisplay(row, channel)) return;
  Row &r = rows[row];
  DisplayState &d = r.displays[channel];
  Telemetry &s = stats[row*3 + channel];
  uint32_t previousErrors = s.errors.load();
  uint32_t now = millis();
  if (activeLayout[row].profile == BUSY_PROFILE) {
    drawBusy(*r.oled, row*3 + channel, now); // Animated locally; the host sends no frames.
  } else {
    // Rasterize here, not on arrival: only this path guarantees an initialized, isolated buffer.
    if (activeLayout[row].profile == GENERATED_PROFILE &&
        r.rasterized[channel] != activeLayout[row].revision) {
      rasterizeLabel(row, channel);
      r.rasterized[channel] = activeLayout[row].revision;
    }
    const uint8_t *background = activeLayout[row].profile == GENERATED_PROFILE
        ? r.textBitmap[channel] : activeLayout[row].profile == 8
        ? sixIconCatalog[activeLayout[row].icons[row*3+channel]]
        : sixProfiles[activeLayout[row].profile][row*3+channel];
    // Actual elapsed time keeps speed fixed even if bus traffic delays a frame.
    d.wave.frame(now, r.bitmap, background);
    r.oled->clearBuffer();
    r.oled->drawXBMP(0, 0, 64, 32, r.bitmap);
  }
  uint32_t start = micros();
  r.oled->sendBuffer();
  if (s.errors.load() == previousErrors) shownRevision[row*3+channel] = activeLayout[row].revision;
  s.transferUs = micros() - start;
  if (s.frames.load()) s.intervalUs = uint32_t(now - d.lastFrame) * 1000;
  ++s.frames;
  d.lastFrame = now;
  d.dirty = false;
  if (!muxWrite(row, 0)) busFault(row);
  if (s.errors.load() != previousErrors) {
    s.available = false;
    logLine("FAULT KEY %u CH %u CODE %lu SHORT_WRITES %lu (display disabled)\n",
                  row*3+channel+1, channel, (unsigned long)s.lastCode.load(),
                  (unsigned long)s.shortWrites.load());
  }
}
void scanChannels(uint8_t row) {
  // No animation transfers run while this worker performs the scan.
  bool off = muxWrite(row, 0);
  int offMask = -1;
  if (rows[row].wire->requestFrom(MUX_ADDRESSES[row], uint8_t(1)) == 1) offMask = rows[row].wire->read();
  int upstream = -1;
  if (off && offMask == 0) {
    rows[row].wire->beginTransmission(OLED_ADDRESS); upstream = rows[row].wire->endTransmission();
  }
  logLine("SCAN BUS %u OFF MUX_OK %u MASK_READ %d OLED_3C %d\n", row, off ? 1 : 0, offMask, upstream);
  if (!off || offMask != 0) { busFault(row); delay(1); }
  for (uint8_t channel = 0; channel < 8; ++channel) {
    bool written = muxWrite(row, uint8_t(1U << channel));
    int actual = -1;
    if (rows[row].wire->requestFrom(MUX_ADDRESSES[row], uint8_t(1)) == 1)
      actual = rows[row].wire->read();
    int ack3c = -1, ack3d = -1;
    if (written && actual == (1 << channel)) {
      rows[row].wire->beginTransmission(0x3C); ack3c = rows[row].wire->endTransmission();
      rows[row].wire->beginTransmission(0x3D); ack3d = rows[row].wire->endTransmission();
    }
    logLine("SCAN BUS %u CH %u MASK_EXPECT 0x%02X MASK_READ %d MUX_OK %u OLED_3C %d OLED_3D %d\n",
                  row, channel, 1 << channel, actual, written ? 1 : 0, ack3c, ack3d);
    if (!muxWrite(row, 0)) { busFault(row); delay(1); }
  }
  logLine("DONE SCAN BUS %u\n", row);
}
void testDisplay(uint8_t row, uint8_t channel) {
  // Recover/isolate before this single display; do not initialize the other five.
  if (!busReady[row]) { rows[row].wire->end(); prepareBus(row); }
  if (!initializeDisplay(row, channel)) {
    logLine("TEST KEY %u CH %u INIT_FAILED PROBE %lu\n", row*3+channel+1, channel,
                  (unsigned long)stats[row*3 + channel].probeCode.load());
    if (!muxWrite(row, 0)) busFault(row);
    return;
  }
  U8G2 &d = *rows[row].oled;
  uint32_t before = stats[row*3 + channel].errors.load();
  d.clearBuffer();
  d.drawFrame(0, 0, 64, 32);
  for (uint8_t x = 2; x < 62; x += 4) d.drawBox(x, 2, 2, 6);
  d.setFont(u8g2_font_6x10_tf);
  char label[12]; snprintf(label, sizeof(label), "KEY %u", row*3+channel+1);
  d.drawStr(17, 22, label);
  // Exactly one frame, then idle: no continuous data or animation queue.
  d.sendBuffer();
  bool off = muxWrite(row, 0);
  logLine("TEST KEY %u CH %u NEW_ERRORS %lu SHORT_WRITES %lu MAX_BYTES %lu LAST_CODE %lu\n",
                row*3+channel+1, channel, (unsigned long)(stats[row*3 + channel].errors.load()-before),
                (unsigned long)stats[row*3 + channel].shortWrites.load(),
                (unsigned long)stats[row*3 + channel].maxBytes.load(),
                (unsigned long)stats[row*3 + channel].lastCode.load());
  if (stats[row*3 + channel].errors.load() != before) stats[row*3 + channel].available = false;
  if (!off) busFault(row);
}
void debugCommand(uint8_t row, DebugRequest request) {
  paused[row] = true;
  for (auto &d : rows[row].displays) d.wave.count = 0;
  if (request.command == SCAN) scanChannels(row);
  else if (request.command == TEST) {
    if (request.value < 0) {
      for (uint8_t i=0; i<3; ++i) testDisplay(row, i);
    } else if (request.value / 3 == row) testDisplay(row, request.value % 3);
    logLine("DONE TEST BUS %u (paused)\n", row);
  } else if (request.command == RATE || request.command == REINIT) {
    // Reset mux/bus and retry initialization; historical errors do not block recovery.
    for (uint8_t i=row*3; i<row*3+3; ++i) stats[i].available = false;
    rows[row].wire->end();
    if (request.command == RATE) busHz[row] = request.value;
    reverseInit[row] = request.command == REINIT && request.value == 1;
    initRow(row);
    logLine("DONE REINIT BUS %u HZ %lu REVERSE %u (paused)\n", row, (unsigned long)busHz[row].load(), reverseInit[row] ? 1 : 0);
  } else if (request.command == RUN) {
    for (auto &d : rows[row].displays) d.dirty = true;
    paused[row] = false;
    logLine("DONE RUN BUS %u\n", row);
  }
}
void displayWorker(void *argument) {
  uint8_t row = static_cast<uint8_t>(reinterpret_cast<uintptr_t>(argument));
  Row &r = rows[row];
  initRow(row);
  uint8_t channel = 0;
  for (;;) {
    Layout layout;
    if (xQueueReceive(layoutQueue[row], &layout, 0) == pdTRUE) {
      if (layout.revision != activeLayout[row].revision || layout.profile != activeLayout[row].profile) {
        activeLayout[row] = layout;
        for (auto &display : r.displays) display.dirty = true;
      }
    }
    DebugRequest request;
    if (xQueueReceive(debugQueue[row], &request, 0) == pdTRUE) debugCommand(row, request);
    Press press;
    // Bounded queue drain; the worker exclusively owns all wave state and the shared buffer.
    for (uint8_t n = 0; n < 32 && xQueueReceive(r.queue, &press, 0) == pdTRUE; ++n) {
      if (!paused[row] && stats[row*3 + press.channel].available) {
        r.displays[press.channel].wave.trigger(press.at);
        r.displays[press.channel].dirty = true;
      }
    }
    DisplayState &d = r.displays[channel];
    if (!paused[row] && busReady[row] && stats[row*3 + channel].available &&
        (d.dirty || d.wave.count || activeLayout[row].profile == BUSY_PROFILE) &&
        uint32_t(millis() - d.lastFrame) >= FRAME_MS)
      render(row, channel);
    channel = (channel + 1) % 3;
    vTaskDelay(1); // Yield so button/serial handling remains responsive.
  }
}
bool trigger(uint8_t key) {
  if (key >= KEY_COUNT || paused[key/3] || !busReady[key/3] || !stats[key].available) return false;
  Press press = {uint8_t(key%3), millis()};
  bool sent = rows[key/3].queue && xQueueSend(rows[key/3].queue, &press, 0) == pdTRUE;
  if (!sent) ++queueDrops;
  return sent;
}
void sampleButtons() {
  uint32_t now = millis();
  for (uint8_t i = 0; i < KEY_COUNT; ++i) {
    Button &b = buttons[i];
    bool raw = digitalRead(BUTTON_PINS[i]);
    if (raw != b.raw) { b.raw = raw; b.changed = now; }
    if (raw != b.stable && uint32_t(now - b.changed) >= 25) {
      b.stable = raw;
      if (raw == LOW && !trigger(i)) logLine("ERROR trigger %u paused, unavailable or queue full\n", i);
      logLine("BUTTON %u %u\n", i, raw == LOW ? 1 : 0);
      if (raw == LOW && companionActive && !paused[i/3] && stats[i].available && busReady[i/3]) {
        if (++pressSequence == 0) ++pressSequence;
        logLine("PRESS6 %lu %lu %u\n", (unsigned long)pressSequence,
                (unsigned long)shownRevision[i].load(), i);
      }
    }
  }
}
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
void loop() {
  if (companionActive && uint32_t(millis() - lastLayout) > 1500) {
    companionActive = false;
    Layout idle = {};
    for (uint8_t row=0; row<2; ++row)
      if (layoutQueue[row]) xQueueOverwrite(layoutQueue[row], &idle);
  }
  sampleButtons();
  for (int n = 0; n < 64 && Serial.available(); ++n) {
    char c = Serial.read();
    if (c == '\n') {
      if (overflow) logLine("ERROR line too long\n");
      else { input[used] = 0; command(input); }
      used = 0; overflow = false;
    } else if (c != '\r') {
      if (used < sizeof(input) - 1) input[used++] = c;
      else overflow = true;
    }
  }
  delay(1);
}

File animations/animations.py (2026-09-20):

#!/usr/bin/env python3
"""Keymaeleon animation lab: standalone preview and optional USB control."""
import math
import time
import tkinter as tk
from tkinter import ttk

MAX_WAVES = 32

MODES = ('Invert (hold)', 'Bottom wave', 'Center ripple', 'Wipe', 'Dissolve', 'Sparkle')
DESCRIPTIONS = (
    'Inverts every pixel while the physical button is held. Test flashes for 450 ms.',
    'Each press adds a bottom wave. Rapid presses create overlapping rings.',
    'A circular ripple expands from the center of the display.',
    'A vertical band sweeps across the display from left to right.',
    'Pixels dissolve into an inverted image and then return.',
    'Scattered pixels shimmer across the display. Thickness controls density.',
)


def frame(mode, thickness, speed, elapsed, held=False, wave_ages=None):
    """64×32 monochrome frame; same formulas and limits as the sketch."""
    travel = max(0, elapsed) * speed
    limit = 46 + thickness if mode == 1 else 37 + thickness if mode == 2 else 64 + thickness if mode == 3 else 64
    active = elapsed >= 0 and travel < limit
    rings = []
    if mode == 1:
        ages = [elapsed] if wave_ages is None else wave_ages
        rings = [age * speed for age in ages if 0 <= age * speed < limit]
        active = bool(rings)
    pixels = []
    for y in range(32):
        row = []
        for x in range(64):
            base = (((y == 1 or y == 30) and 2 <= x <= 61) or
                    ((x == 1 or x == 62) and 2 <= y <= 29) or
                    (25 <= x <= 42 and abs(y - 16) <= (42 - x) * 2 // 3))
            flip = mode == 0 and held
            noise = (x * 37 + y * 73 + x * y * 13) % 101
            if active and mode:
                if mode in (1, 2):
                    distance = math.hypot(x - 31.5, y - (31 if mode == 1 else 15.5))
                    flip = (any(radius - thickness < distance <= radius for radius in rings)
                            if mode == 1 else travel - thickness < distance <= travel)
                elif mode == 3:
                    flip = travel - thickness < x <= travel
                elif mode == 4:
                    flip = noise < 100 * math.sin(math.pi * travel / 64)
                else:
                    flip = (noise + int(travel / 3) * 17) % 101 < thickness and (x + y) % 3 == 0
            row.append(bool(base) != bool(flip))
        pixels.append(row)
    return pixels


class AnimationLab:
    def __init__(self, root):
        self.root = root
        self.port = None
        self.ready = False
        self.pending = bytearray()
        self.started = [None, None]
        self.waves = [[], []]
        self.held = [False, False]
        self.pulse_until = [0, 0]
        self.last_hello = 0
        self.last_stats = 0
        self.apply_job = None
        self.connected_at = 0
        self.mode = tk.StringVar(value=MODES[1])
        self.thickness = tk.IntVar(value=5)
        self.speed = tk.IntVar(value=45)
        self.status = tk.StringVar(value='Preview mode — connect a board when ready.')
        self.timing = tk.StringVar(value='Hardware transfer timing appears when connected.')
        self.description = tk.StringVar(value=DESCRIPTIONS[1])
        self.port_name = tk.StringVar()
        root.title('Keymaeleon · Animation Lab')
        root.resizable(False, False)
        outer = ttk.Frame(root, padding=20)
        outer.pack(fill='both', expand=True)
        ttk.Label(outer, text='Animation Lab', font=('Sans', 20, 'bold')).pack(anchor='w')
        ttk.Label(outer, text='64 × 32 OLEDs · press either key to animate its display').pack(anchor='w', pady=(2, 16))
        connection = ttk.Frame(outer)
        connection.pack(fill='x')
        self.ports = ttk.Combobox(connection, textvariable=self.port_name, width=32)
        self.ports.pack(side='left')
        ttk.Button(connection, text='Refresh ports', command=self.refresh_ports).pack(side='left', padx=6)
        self.connect_button = ttk.Button(connection, text='Connect', command=self.connect)
        self.connect_button.pack(side='left')
        previews = ttk.Frame(outer)
        previews.pack(pady=20)
        self.images = []
        for i, name in enumerate(('Left key · D2', 'Right key · D3')):
            panel = ttk.Frame(previews)
            panel.pack(side='left', padx=8)
            ttk.Label(panel, text=name).pack(pady=(0, 8))
            image = tk.PhotoImage(width=64, height=32)
            label = ttk.Label(panel)
            label.pack()
            self.images.append((image, label))
            ttk.Button(panel, text='Test press', command=lambda key=i: self.trigger(key)).pack(pady=8)
        controls = ttk.Frame(outer)
        controls.pack(fill='x')
        ttk.Label(controls, text='Animation').grid(row=0, column=0, sticky='w', padx=(0, 12))
        choices = ttk.Combobox(controls, textvariable=self.mode, values=MODES, state='readonly', width=26)
        choices.grid(row=0, column=1, sticky='w')
        choices.bind('<<ComboboxSelected>>', self.settings_changed)
        for row, (title, variable, low, high) in enumerate((
            ('Thickness / density', self.thickness, 1, 16),
            ('Speed (pixels/sec)', self.speed, 5, 160)), 1):
            ttk.Label(controls, text=title).grid(row=row, column=0, sticky='w')
            tk.Scale(controls, variable=variable, from_=low, to=high, orient='horizontal',
                     length=320, command=self.settings_changed).grid(row=row, column=1)
        ttk.Label(outer, textvariable=self.description, wraplength=560).pack(anchor='w', pady=(12, 6))
        ttk.Label(outer, text='Settings apply to both keys. Bottom waves stack with each press.\n'
                  'Effects run on the board; USB is only needed to change settings.').pack(anchor='w')
        ttk.Label(outer, textvariable=self.status, wraplength=560).pack(anchor='w', pady=(16, 0))
        ttk.Label(outer, textvariable=self.timing, wraplength=560).pack(anchor='w', pady=(6, 0))
        self.refresh_ports()
        root.protocol('WM_DELETE_WINDOW', self.close)
        root.after(33, self.tick)

    def refresh_ports(self):
        try:
            from serial.tools import list_ports
            devices = [p.device for p in list_ports.comports()]
            self.ports['values'] = devices
            if devices and not self.port_name.get():
                self.port_name.set(devices[0])
        except ImportError:
            self.status.set('Preview available. Install pyserial to connect a board.')

    def disconnect(self, message='Disconnected — preview mode.'):
        if self.port:
            self.port.close()
        self.port = None
        self.ready = False
        self.pending.clear()
        self.held = [False, False]
        self.connect_button.configure(text='Connect')
        self.status.set(message)
        self.timing.set('Hardware transfer timing appears when connected.')
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

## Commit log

2026-09-19 Add context-aware six-key backend
    The service that decides which six key functions a developer needs next,
    derived from observed state rather than a configured layout.
    Context sources:
    - server/editor.js VS Code bridge: active file, diagnostics, unsaved count,
    focus, and a command queue the extension acknowledges
    - server/agents.js Codex/Claude session transcripts reduced to a lifecycle —
    working vs. finished, patched files, last command exit code
    - server/runtime.js Git reads, content fingerprinting for staleness, and a real
    test process with TAP-aware pass/fail/runner-error handling
    - server/voice.js Local FFmpeg cap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
2026-09-19 Add minimal display client for the six keys
    The native panel loads `/?popup=1&native=1` into its WebView, so without a
    page there the monitor window was blank. This draws the caps.
    It holds no state. `render` re-runs the same `liveLayout` over the published
    context that the backend used, so a cap always matches what `POST /api/key`
    will dispatch, and presses carry the `layout_revision` they were drawn from —
    a press that raced a context change comes back 409 rather than firing the
    action that replaced it.
    Disabled keys keep their slot and show why, rather than vanishing. The footer
    shows the layer's own reason ("Codex finished and changed 2 files"), which is
    the claim worth being able to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
2026-09-19 Plan the demo: scripted beats, real layout engine
    Pivot from 'make the whole pipeline live' to a viable two-minute demo on real
    hardware. A scene runner walks a twelve-beat web-development story; each beat
    builds a real context and resolves it through the existing live.js, so the six
    keys shown are genuinely what the system would pick rather than hand-drawn.
    The events are staged; the decision is not, and the talk track says so.
    Anchors on the ESP32 firmware and Icons6.h, which work today. Records what
    has to be built: per-key icon IDs alongside the existing SET6 profile command,
    an icon generator to replace the missing tools/generate_six_icons.py, the
    scene runner, and a macOS serial bridg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
2026-09-19 Add the 3:30 demo story and rework the build plan around it
    DEMO.md: a checkout page renders $NaN. The unit test passes a number, the
    real API returns a string, so Codex fixes the rounding, the test goes green,
    and the page is still broken. The wall is the agent's blind spot -- it never
    sees the browser -- which is also the argument for the keyboard.
    Nine beats, 210 seconds, with the talk track and an explicit real-vs-staged
    split. Three beats carry it: the dimmed Run Tests key at 0:20 that refuses
    and says why, the silence at 2:00, and the decision surface at 2:25 where
    there is no single next move and six keys beat a menu.
    PLAN.md: reordered around that demo, and corrected. The VS Code e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
2026-09-19 Add the demo checkout app and browser error reporting
    Build steps 1 and 2 from PLAN.md, and switch the demo target to Linux.
    The bug is shaped so the wall is a property of the code rather than the
    script. src/format.js has a rounding defect three tests catch and an agent
    fixes in one line. src/cart.js multiplies the API's display string ("$149.00")
    by a quantity and yields NaN, and no test touches it because every fixture
    builds items with numeric prices.
    before the fix 4 passed, 2 failed page shows $NaN
    after the fix 6 passed, 0 failed page shows $NaN
    Verified both states. The agent's fix is real and the application is exactly
    as broken as it was, because it read the source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
2026-09-19 Connect the backend to the keyboard
    The two halves of this repo did not touch. Now the backend's resolved layout
    reaches the caps, and a press on the caps reaches the backend.
    tools/generate_six_icons.py replaces the file the firmware README referenced
    but that was never committed. It recovers the 21 shipping pictograms from the
    existing header byte for byte rather than redrawing them -- they are known
    good on real hardware and the source artwork is gone -- then draws 13 new ones
    for the developer layers from vector primitives, no third-party dependency.
    Verified all 21 preserved and sixProfiles identical.
    Firmware gains SETK6 <revision> <i0..i5> beside SET6, which now expands a
    profile in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
    [Keymaeleon6.ino]
2026-09-19 Add USAGE.md: running the backend with VS Code and the keyboard
    An end-to-end setup guide, verified from a cold start rather than written from
    memory: backend adopting a focused workspace, resolved keys coming back, and
    the caps rendering in the terminal.
    Leads with which of the three programs decides anything. Only the backend does.
    The extension is a sensor and a pair of hands, the bridge is a display, and if
    either worked out the keys for itself they would drift until a cap lied about
    what it does.
    Documents the Linux requirement that requireForeground be false, the TAP-aware
    test classification, and the order to check things on first hardware contact --
    HELLO answering COMPANION_2 and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
2026-09-19 Document every key in every situation in the extension README
    Fifteen layers with their six labels, generated by running each context through
    live.js rather than transcribed, so the table cannot drift from the code that
    decides. Plus the ordered chain that picks a layer, and every reason a key can
    be dimmed with the exact string shown.
    Records two things the table makes visible. The agent-review layer puts a diff
    of the specific patched file on U, parameterised, not a generic diff -- and only
    when the agent's own transcript says the turn finished and Git sees a dirty
    tree. And tests-failed currently resolves to the same six keys as ordinary
    editing, differing only in its reason: the layer e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
